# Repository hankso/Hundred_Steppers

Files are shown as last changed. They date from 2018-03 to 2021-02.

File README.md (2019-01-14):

## Hundred Steppers
An arduino library to control hundreds of steppers with as less pins or
arduinos as possible.

[74HC595](https://www.arduino.cc/en/Tutorial/ShiftOut) is needed to extend the
GPIO number of arduino.

To offer enough current for steppers, you may need UNL2803(8 channel NPN
darlington triodes, 500mA@50V max)

If you have used arduino library
[`Stepper`](https://www.arduino.cc/en/Reference/Stepper) and
[`Adafruit_NeoPixel`](https://github.com/adafruit/Adafruit_NeoPixel) before,
you may find this API familiar because I name these functions similar with them.

## How to use
- Download zip file
- Unzip in your arduino libraries directory. It can be `~/arduino/libraries`
or something like `C:\Program Files\Arduino\libraries`.
- open your arduino IDE and try include library `include <Hundred_Steppers.h>`,
also there is an [example](example/control_steppers) available.

## Hardware
- There is an example hardware design available in `Eagle` format.
- 74HC595 pins
    - ST_CP --> latchPin
    - SH_CP --> clockPin
    - DS --> dataPin
    - OE --> enablePin
    - MR --> clearPin

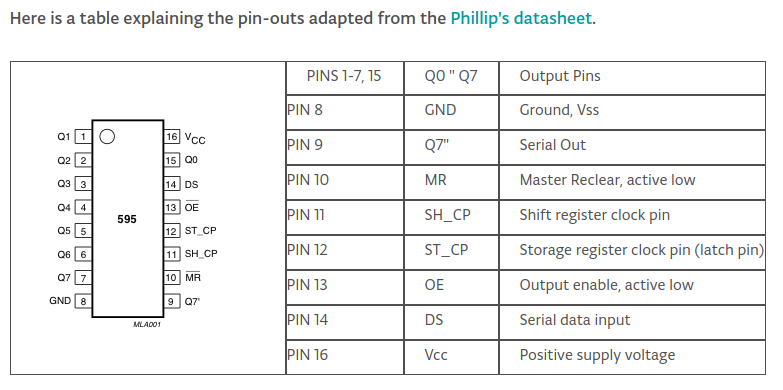
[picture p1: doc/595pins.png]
74HC595


## API
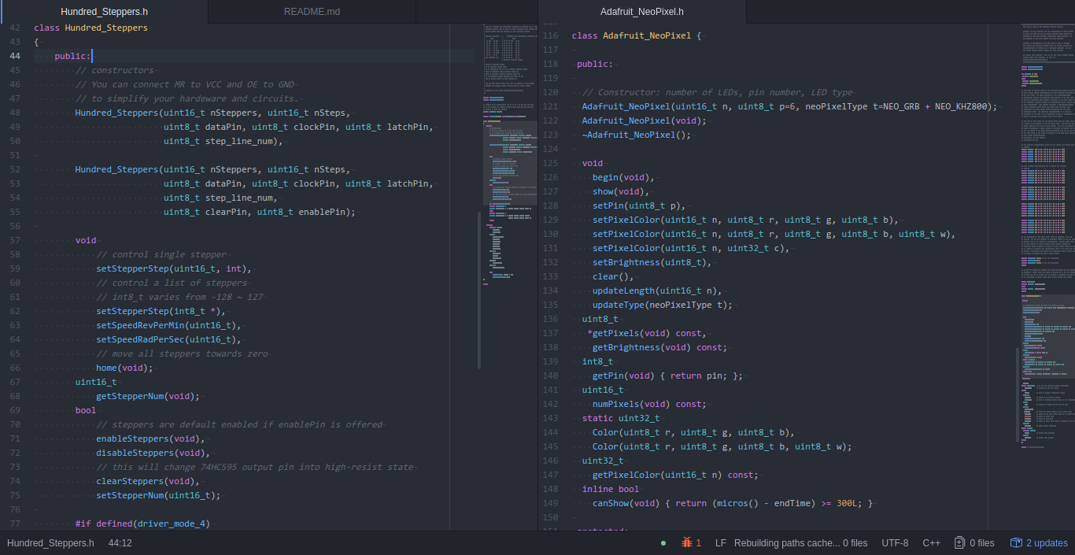
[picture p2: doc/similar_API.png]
similar API


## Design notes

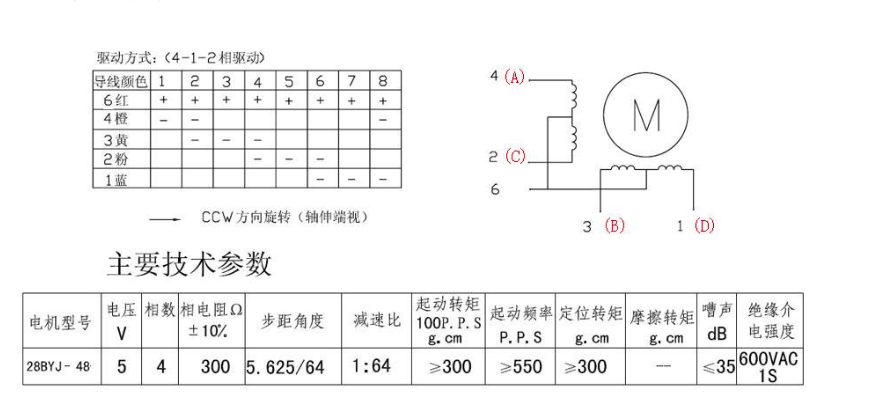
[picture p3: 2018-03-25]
doc/28BYJ48_stepper.png

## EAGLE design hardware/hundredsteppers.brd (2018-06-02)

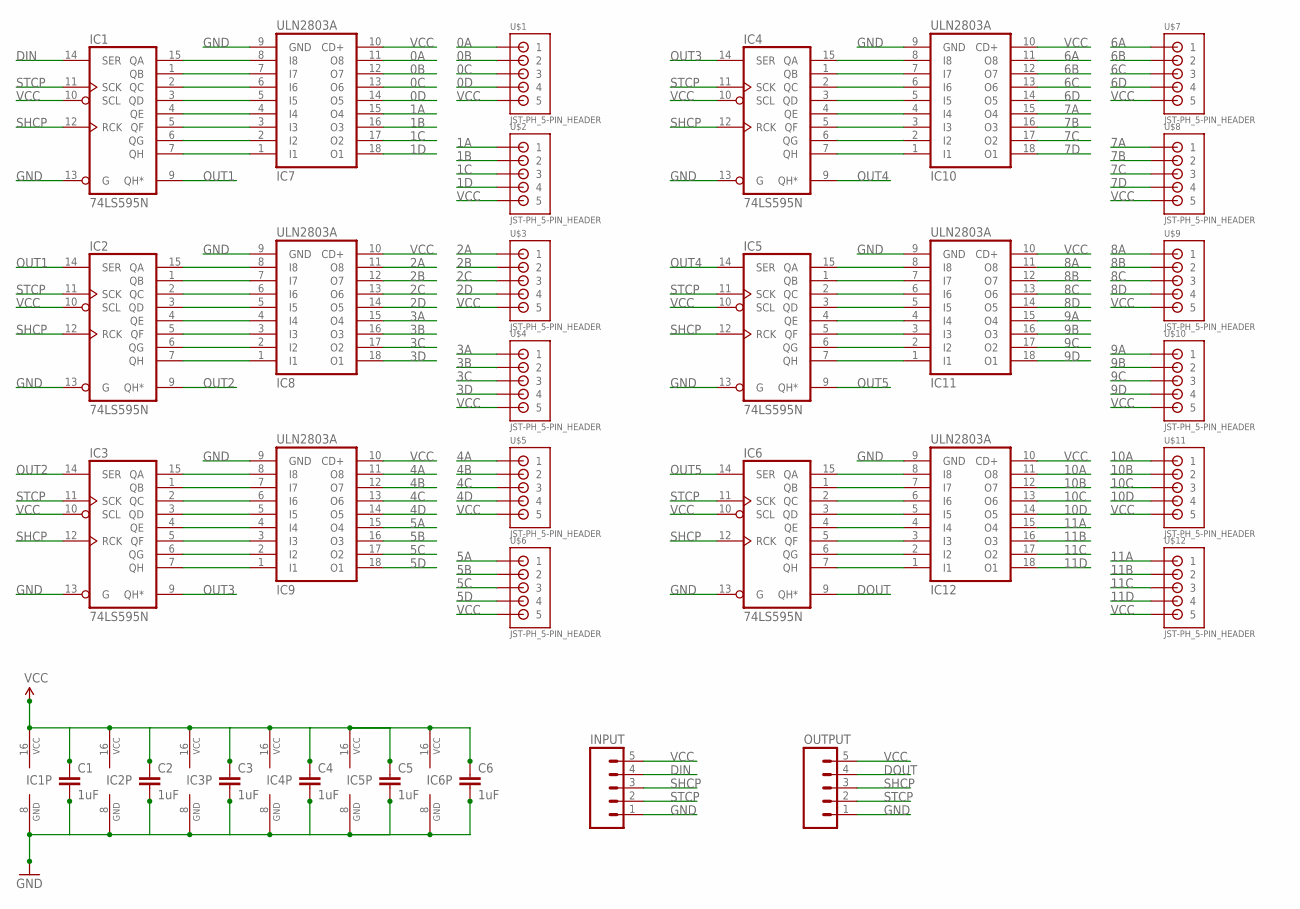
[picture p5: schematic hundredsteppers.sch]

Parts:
C1, C2, C3, C4, C5, C6: 1uF; 0805
IC1, IC2, IC3, IC4, IC5, IC6: 74LS595N; DIL16
IC7, IC8, IC9, IC10, IC11, IC12: ULN2803A; DIL18
INPUT: M05PTH; 1X05
OUTPUT: M05PTH; 1X05
U$1, U$2, U$3, U$4, U$5, U$6, U$7, U$8, U$9, U$10, U$11, U$12: JST-PH_5-PIN_HEADER; JST_B5B-PH_HEADER

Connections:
0A: IC7.11 (O8), U$1.P1 (1)
0B: IC7.12 (O7), U$1.P2 (2)
0C: IC7.13 (O6), U$1.P3 (3)
0D: IC7.14 (O5), U$1.P4 (4)
1A: IC7.15 (O4), U$2.P1 (1)
1B: IC7.16 (O3), U$2.P2 (2)
1C: IC7.17 (O2), U$2.P3 (3)
1D: IC7.18 (O1), U$2.P4 (4)
2A: IC8.11 (O8), U$3.P1 (1)
2B: IC8.12 (O7), U$3.P2 (2)
2C: IC8.13 (O6), U$3.P3 (3)
2D: IC8.14 (O5), U$3.P4 (4)
3A: IC8.15 (O4), U$4.P1 (1)
3B: IC8.16 (O3), U$4.P2 (2)
3C: IC8.17 (O2), U$4.P3 (3)
3D: IC8.18 (O1), U$4.P4 (4)
4A: IC9.11 (O8), U$5.P1 (1)
4B: IC9.12 (O7), U$5.P2 (2)
4C: IC9.13 (O6), U$5.P3 (3)
4D: IC9.14 (O5), U$5.P4 (4)
5A: IC9.15 (O4), U$6.P1 (1)
5B: IC9.16 (O3), U$6.P2 (2)
5C: IC9.17 (O2), U$6.P3 (3)
5D: IC9.18 (O1), U$6.P4 (4)
6A: IC10.11 (O8), U$7.P1 (1)
6B: IC10.12 (O7), U$7.P2 (2)
6C: IC10.13 (O6), U$7.P3 (3)
6D: IC10.14 (O5), U$7.P4 (4)
7A: IC10.15 (O4), U$8.P1 (1)
7B: IC10.16 (O3), U$8.P2 (2)
7C: IC10.17 (O2), U$8.P3 (3)
7D: IC10.18 (O1), U$8.P4 (4)
8A: IC11.11 (O8), U$9.P1 (1)
8B: IC11.12 (O7), U$9.P2 (2)
8C: IC11.13 (O6), U$9.P3 (3)
8D: IC11.14 (O5), U$9.P4 (4)
9A: IC11.15 (O4), U$10.P1 (1)
9B: IC11.16 (O3), U$10.P2 (2)
9C: IC11.17 (O2), U$10.P3 (3)
9D: IC11.18 (O1), U$10.P4 (4)
10A: IC12.11 (O8), U$11.P1 (1)
10B: IC12.12 (O7), U$11.P2 (2)
10C: IC12.13 (O6), U$11.P3 (3)
10D: IC12.14 (O5), U$11.P4 (4)
11A: IC12.15 (O4), U$12.P1 (1)
11B: IC12.16 (O3), U$12.P2 (2)
11C: IC12.17 (O2), U$12.P3 (3)
11D: IC12.18 (O1), U$12.P4 (4)
DIN: IC1.14 (SER), INPUT.4
DOUT: IC6.9 (QH*), OUTPUT.4
GND: C1.2, C2.2, C3.2, C4.2, C5.2, C6.2, IC1.8 (GND), IC1.13 (G), IC2.8 (GND), IC2.13 (G), IC3.8 (GND), IC3.13 (G), IC4.8 (GND), IC4.13 (G), IC5.8 (GND), IC5.13 (G), IC6.8 (GND), IC6.13 (G), IC7.9 (GND), IC8.9 (GND), IC9.9 (GND), IC10.9 (GND), IC11.9 (GND), IC12.9 (GND), INPUT.1, OUTPUT.1
unnamed: IC1.15 (QA), IC7.8 (I8)
unnamed: IC1.1 (QB), IC7.7 (I7)
unnamed: IC1.2 (QC), IC7.6 (I6)
unnamed: IC1.3 (QD), IC7.5 (I5)
unnamed: IC1.4 (QE), IC7.4 (I4)
unnamed: IC1.5 (QF), IC7.3 (I3)
unnamed: IC1.6 (QG), IC7.2 (I2)
unnamed: IC1.7 (QH), IC7.1 (I1)
unnamed: IC2.15 (QA), IC8.8 (I8)
unnamed: IC2.1 (QB), IC8.7 (I7)
unnamed: IC2.2 (QC), IC8.6 (I6)
unnamed: IC2.3 (QD), IC8.5 (I5)
unnamed: IC2.4 (QE), IC8.4 (I4)
unnamed: IC2.5 (QF), IC8.3 (I3)
unnamed: IC2.6 (QG), IC8.2 (I2)
unnamed: IC2.7 (QH), IC8.1 (I1)
unnamed: IC3.15 (QA), IC9.8 (I8)
unnamed: IC3.1 (QB), IC9.7 (I7)
unnamed: IC3.2 (QC), IC9.6 (I6)
unnamed: IC3.3 (QD), IC9.5 (I5)
unnamed: IC3.4 (QE), IC9.4 (I4)
unnamed: IC3.5 (QF), IC9.3 (I3)
unnamed: IC3.6 (QG), IC9.2 (I2)
unnamed: IC3.7 (QH), IC9.1 (I1)
unnamed: IC4.15 (QA), IC10.8 (I8)
unnamed: IC4.1 (QB), IC10.7 (I7)
unnamed: IC4.2 (QC), IC10.6 (I6)
unnamed: IC4.3 (QD), IC10.5 (I5)
unnamed: IC4.4 (QE), IC10.4 (I4)
unnamed: IC4.5 (QF), IC10.3 (I3)
unnamed: IC4.6 (QG), IC10.2 (I2)
unnamed: IC4.7 (QH), IC10.1 (I1)
unnamed: IC5.15 (QA), IC11.8 (I8)
unnamed: IC5.1 (QB), IC11.7 (I7)
unnamed: IC5.2 (QC), IC11.6 (I6)
unnamed: IC5.3 (QD), IC11.5 (I5)
unnamed: IC5.4 (QE), IC11.4 (I4)
unnamed: IC5.5 (QF), IC11.3 (I3)
unnamed: IC5.6 (QG), IC11.2 (I2)
unnamed: IC5.7 (QH), IC11.1 (I1)
unnamed: IC6.15 (QA), IC12.8 (I8)
unnamed: IC6.1 (QB), IC12.7 (I7)
unnamed: IC6.2 (QC), IC12.6 (I6)
unnamed: IC6.3 (QD), IC12.5 (I5)
unnamed: IC6.4 (QE), IC12.4 (I4)
unnamed: IC6.5 (QF), IC12.3 (I3)
unnamed: IC6.6 (QG), IC12.2 (I2)
unnamed: IC6.7 (QH), IC12.1 (I1)
OUT1: IC1.9 (QH*), IC2.14 (SER)
OUT2: IC2.9 (QH*), IC3.14 (SER)
OUT3: IC3.9 (QH*), IC4.14 (SER)
OUT4: IC4.9 (QH*), IC5.14 (SER)
OUT5: IC5.9 (QH*), IC6.14 (SER)
SHCP: IC1.12 (RCK), IC2.12 (RCK), IC3.12 (RCK), IC4.12 (RCK), IC5.12 (RCK), IC6.12 (RCK), INPUT.3, OUTPUT.3
STCP: IC1.11 (SCK), IC2.11 (SCK), IC3.11 (SCK), IC4.11 (SCK), IC5.11 (SCK), IC6.11 (SCK), INPUT.2, OUTPUT.2
VCC: C1.1, C2.1, C3.1, C4.1, C5.1, C6.1, IC1.10 (SCL), IC1.16 (VCC), IC2.10 (SCL), IC2.16 (VCC), IC3.10 (SCL), IC3.16 (VCC), IC4.10 (SCL), IC4.16 (VCC), IC5.10 (SCL), IC5.16 (VCC), IC6.10 (SCL), IC6.16 (VCC), IC7.10 (CD+), IC8.10 (CD+), IC9.10 (CD+), IC10.10 (CD+), IC11.10 (CD+), IC12.10 (CD+), INPUT.5, OUTPUT.5, U$1.P5 (5), U$2.P5 (5), U$3.P5 (5), U$4.P5 (5), U$5.P5 (5), U$6.P5 (5), U$7.P5 (5), U$8.P5 (5), U$9.P5 (5), U$10.P5 (5), U$11.P5 (5), U$12.P5 (5)

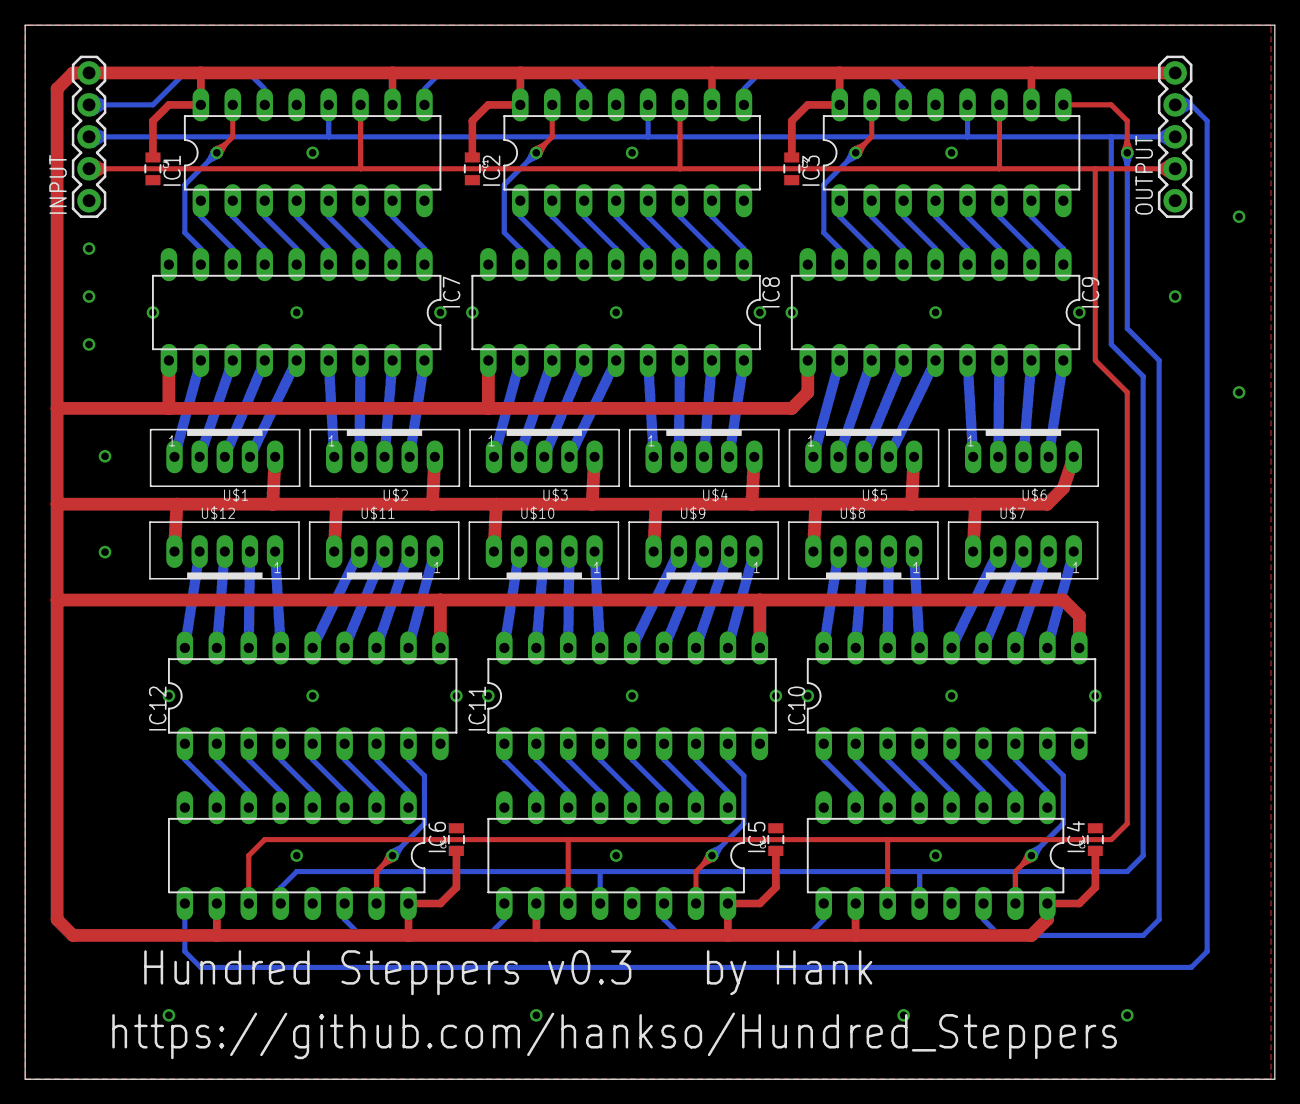
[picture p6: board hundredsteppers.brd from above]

Board: 2 copper layers, 99.4 x 83.8 mm, 32 parts (0 on the bottom side), 107 nets.

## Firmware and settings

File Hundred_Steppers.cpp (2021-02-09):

/*
 * This is a library for controlling hundreds of steppers with a single
 * arduino. 74HC595 chip is used to extend arduino's GPIO number, which
 * accept serial data and transfer it into parallel output.
 *
 * 74HC595 pin-outs:    |     UNL2803(8 NPN darlington, 50V@500mA max):
 *       ____           |            ____
 *  Q1 -|o   |- VCC     | Q0 -- I1 -|o   |- O1
 *  Q2 -|    |- Q0      | Q1 -- I2 -|    |- O2
 *  Q3 -|    |- DS      | Q2 -- I3 -|    |- O3
 *  Q4 -|    |- OE      | Q3 -- I4 -|    |- O4
 *  Q5 -|    |- STCP    | Q4 -- I5 -|    |- O5
 *  Q6 -|    |- SHCP    | Q5 -- I6 -|    |- O6
 *  Q7 -|    |- MR      | Q6 -- I7 -|    |- O7
 * GND -|____|- Q7'     | Q7 -- I8 -|    |- O8
 *                      | GND--GND -|____|- COMMON -- VCC
 *
 * Q0-Q7 -- parallel output
 * DS -- dataPin, serial input
 * OE -- enablePin, set to LOW to enable parallel output
 * SHCP -- clockPin, SHift register Clock Pin
 * STCP -- latchPin, STorage register Clock Pin
 * MR -- clearPin, Master Reclear, set Q0-Q7 to LOW
 * Q7' -- serial output to next cascaded DS
 *
 * You may need extra driver chip such as UNL2803 to offer enough
 * current for stepper. Simply connect pins as showed above.
 *
 * Writtern by Hank @page https://github.com/hankso
 *
 * Stepper `24BYJ48` pin value table
 * +---------+-------------------------------+
 * |color pin| 1 | 2 | 3 | 4 | 5 | 6 | 7 | 8 |
 * +---------+-------------------------------+
 * |red     5| H | H | H | H | H | H | H | H |
 * |orange  4| L | L |   |   |   |   |   | L |
 * |yellow  3|   | L | L | L |   |   |   |   |
 * |pink    2|   |   |   | L | L | L |   |   |
 * |blue    1|   |   |   |   |   | L | L | L |
 * +---------+-------------------------------+
 */

#include <Arduino.h>
#include "Hundred_Steppers.h"

Hundred_Steppers::Hundred_Steppers(
        uint16_t nSteppers, uint16_t nSteps,
        uint8_t dataPin, uint8_t clockPin, uint8_t latchPin,
        uint8_t clearPin, uint8_t enablePin,
        uint8_t nStepperLines, uint8_t driveMode, uint8_t speed)
{
    // steppers num
    this->nSteppers = nSteppers;

    // init steppers' step table full of 0
    // stepType: this is defined in head file Hundred_Steppers.h
    this->stepTable = (stepType *)calloc(nSteppers, sizeof(stepType));

    // get pin registers pointer, these GPIO are frequently used.
    this->dataReg   = portOutputRegister(digitalPinToPort(dataPin));
    this->clockReg  = portOutputRegister(digitalPinToPort(clockPin));
    this->latchReg  = portOutputRegister(digitalPinToPort(latchPin));
    this->dataMask  = digitalPinToBitMask(dataPin);
    this->clockMask = digitalPinToBitMask(clockPin);
    this->latchMask = digitalPinToBitMask(latchPin);
    pinMode(dataPin, OUTPUT);
    pinMode(clockPin, OUTPUT);
    pinMode(latchPin, OUTPUT);
    *dataReg &= ~dataMask;
    *clockReg &= ~clockMask;
    *latchReg &= ~latchMask;

    // not necessary pins, also not frequently used.
    if (clearPin != -1)
    {
        this->clearPin = clearPin;
        pinMode(clearPin, OUTPUT);
        digitalWrite(clearPin, HIGH);
    } else this->clearPin = 0;
    if (enablePin != -1)
    {
        this->enablePin = enablePin;
        pinMode(enablePin, OUTPUT);
        digitalWrite(enablePin, LOW);
    } else this->enablePin = 0;

    this->lastTime = micros();
    this->nStepperLines = nStepperLines;
    this->nSteps = nSteps;

    // driver mode
    this->driveMode = driveMode;
    if (driveMode == 4)
    {
        this->cmdList = new uint8_t[4] { B1110, B1101, B1011, B0111 };
    }
    else if (driveMode == 8)
    {
        this->cmdList = new uint8_t[8] { B1110, B1100, B1101, B1001,
                                         B1011, B0011, B0111, B0110 };
    }

    setSpeedRevPerMin(speed);
}

bool Hundred_Steppers::enableSteppers(void)
{
    if (enablePin)
    {
        digitalWrite(enablePin, LOW);
        return true;
    }
    return false;
}

bool Hundred_Steppers::disableSteppers(void)
{
    if (enablePin)
    {
        digitalWrite(enablePin, HIGH);
        return true;
    }
    return false;
}

bool Hundred_Steppers::clearShiftStorage(void)
{
    if (clearPin)
    {
        digitalWrite(clearPin, LOW);
        delay(10);
        digitalWrite(clearPin, HIGH);
        return true;
    }
    return false;
}

void Hundred_Steppers::setSpeedRevPerMin(uint16_t n)
{
    // speedDelay_second * (steps * rev) = 1min
    // speedDelay * steps * rev = 60000000 us
    speedDelay = 60L * 1000L * 1000L / nSteps / n;
}

void Hundred_Steppers::setSpeedRadPerSec(uint16_t n)
{
    // speedDelay_second * steps * rad/2Pi = 1s
    speedDelay = TWO_PI * 1000L * 1000L / nSteps / n;
}

void Hundred_Steppers::setStepperStep(uint16_t n, int steps)
{
    // control single stepper with its index and steps to move
    if (n > nSteppers) return;
    if (steps > 0)
    {
        while (steps--)
        {
            stepTable[n]++;
            doStep(n);
        }
    }
    else if (steps < 0)
    {
        while (steps++)
        {
            stepTable[n]--;
            doStep(n);
        }
    }
}

void Hundred_Steppers::setStepperStep(int * stepsList, uint16_t length)
{
    // control a list of steppers
    length = min(length, nSteppers);
    uint16_t maxChanged;

    // loop until every steps_to_move return to zero
    // e.g. stepsList finally become {0, 0, 0...}
    while (stepsToMove(stepsList, length))
    {
        maxChanged = -1;
        for (uint16_t i = 0; i < length; i++)
        {
            if (stepsList[i] > 0)
            {
                stepsList[i]--;
                stepTable[i]++;
                maxChanged = i;
            }
            else if (stepsList[i] < 0)
            {
                stepsList[i]++;
                stepTable[i]--;
                maxChanged = i;
            }
        }
        if (maxChanged == -1) break;
        doStep(maxChanged);
    }
}

void Hundred_Steppers::home(void)
{
    // Move each steppers to zero position
    // This do exactly setStepperStep(-stepTable)
    stepType stepsList[nSteppers];
    for (uint16_t i = 0; i < nSteppers; i++)
    {
        stepsList[i] = -stepTable[i];
    }
    setStepperStep(stepsList, nSteppers);
}

bool Hundred_Steppers::setStepperNum(uint16_t n)
{
    if (n <= stepTable)
    {
        nSteppers = n;
        return true;
    }
    // resize internal steps array `stepTable`
    stepType * tmp = (stepType *)realloc(stepTable, n * sizeof(stepType));
    if (tmp)
    {
        stepTable = tmp;
        nSteppers = n;
        return true;
    }
    return false;
}

uint16_t Hundred_Steppers::getStepperNum(void)
{
    return nSteppers;
}
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

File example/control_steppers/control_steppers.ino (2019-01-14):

#include <Hundred_Steppers.h>

#define steppers_num     10  // 10 steppers
#define stepper_line_num 4   // 4-wire 5-phase stepper
#define dataPin          2
#define clockPin         3
#define latchPin         4
#define enablePin        -1  // disabled
#define clearPin         -1  // disabled
#define steps_per_rev    int(16 * (360 / 3.75))
#define driveMode        8   // A-AB-B-BC-C-CD-D-DA
//#define driveMode        4   // A-B-C-D

Hundred_Steppers s = Hundred_Steppers(
    steppers_num, steps_per_rev,
    dataPin, clockPin, latchPin, enablePin, clearPin,
    stepper_line_num, driveMode, 20);


String s1 = String("\n\
===============================================\n\
set stepper step one by one\n\
e.g.\n\
    s.setStepperStep(0, 2);\n\
    stepper No.1 will move forward two steps\n\
===============================================");

String s2 = String("\n\
===============================================\n\
set stepper steps by a plus and minus step list\n\
e.g.\n\
    int step_list[5] = {-2, -1, 0, 1, 2};\n\
    s.setStepperStep(step_list);\n\
    +5 means 5 steps forward\n\
    -3 means 3 steps backwar\n\
===============================================");

String s3 = String("\n\
===============================================\n\
enableSteppers\n\
disableSteppers\n\
clearShiftStorage\n\
setStepperNum\n\
getStepperNum\n\
setSpeedRevPerMin\n\
setSpeedRadPerSec\n\
home\n\
===============================================");


void setup() {
    pinMode(13, OUTPUT);
    Serial.begin(115200);
    Serial.println(s1);
    Serial.print("start time(us): ");
    Serial.println(micros());
    for (uint8_t i = 0; i < steppers_num; i++)
    {
       s.setStepperStep(i, 20*i);
       Serial.print("set stepper ");
       Serial.print(i);
       Serial.print(" to step ");
       Serial.println(20*i);
    }
    Serial.print("finish time(us): ");
    Serial.println(micros());
    Serial.println("hit return to continue");
    Serial.readStringUntil('\n');
    while (!Serial.available()) {;}
    Serial.readStringUntil('\n');


    Serial.println(s2);
    Serial.print("start time(us): ");
    Serial.println(micros());
    int step_list[4] = {1000, 800, -800, -1000};
    s.setStepperStep(step_list, 4);
    Serial.print("finish time(us): ");
    Serial.println(micros());
    Serial.println("hit return to continue");
    Serial.readStringUntil('\n');
    while (!Serial.available()) {;}
    Serial.readStringUntil('\n');


    Serial.println(s3);
    Serial.print("enable steppers: ");
    Serial.println(s.enableSteppers() ? "true" : "false");
    Serial.print("clear registers: ");
    Serial.println(s.clearShiftStorage() ? "true" : "false");
    Serial.print("stepper num: ");
    Serial.println(s.getStepperNum());
    Serial.print("set stepper num: ");
    Serial.println(s.setStepperNum(10) ? "true" : "false");
    Serial.print("stepper num: ");
    Serial.println(s.getStepperNum());
    Serial.println("done!");

    s.home();
}

void loop() {
   // put your main code here, to run repeatedly:
   Serial.println("input stepper index and steps to move(e.g. `5, 5` to move No.5 stepper forward 5 steps.): ");
   while (!Serial.available()) {;}
   digitalWrite(13, HIGH);
   uint16_t index = Serial.parseInt();
   int steps_to_move = Serial.parseInt();
   Serial.readStringUntil('\n');
   String tmp = "moving stepper " + String(index) + " " + String(steps_to_move) + " steps";
   Serial.println(tmp);
   s.setStepperStep(index, steps_to_move);
   digitalWrite(13, LOW);
    // int step_list[4] = {1000, 1000, 1000, 1000};
    // s.setStepperStep(step_list, 4);
}

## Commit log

2018-04-13 fix error on PCB
    [hundredsteppers.brd, hundredsteppers.sch]
2018-05-25 only support 5-wires 4-phase stepper
    [hundredsteppers.brd, hundredsteppers.sch]
2018-06-02 bugfix: STCP and SHCP changed
    [hundredsteppers.brd]

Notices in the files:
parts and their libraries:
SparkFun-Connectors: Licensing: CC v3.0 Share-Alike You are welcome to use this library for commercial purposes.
